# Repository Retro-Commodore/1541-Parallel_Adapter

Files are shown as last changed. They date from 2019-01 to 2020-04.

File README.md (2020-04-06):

# RCEU1505 - 1541-Parallel_Adapter
This is an adapter to easier add a parallel port for the Commodore 1541 and 1541-II diskette drive.
You can (and should) read more on Peter's site https://ist.uwaterloo.ca/~schepers/1541par.html

Item list.
* 15CM 10 wire flatcable.
  * or 8 wire flatcable for ZoomFloppy.
* 15pin D-sub female(not the VGA type connector), either solder or for IDC ribbon cable (last one recommended).
* 40 pins IC socket.
* 2 x 20 pins sil header male-male. (turned/tulip recommended).

All items can be found on eBay or your favorite electronics pusher.

**Let the PCB be as thin as possible, otherwise you need thicker washers. Testet is a 0.8mm thick adapter. **

Washers are needed for the 1541-II drive to lift the mechanical parts.
1.6mm (2 x 0.8mm) height with an inner diameter of 4mm is just sufficient to lift the drive.
It hasn't been physically testet on a 1541 drive, if you're intending to use this drive, let me know how it fits, so I can update this document.

Connecting the adapter to ZoomFloppy is described below, if you need to connect the drive to a C64, you should visit Peter's site for more help.

On 1541 shortboard the chip is UC3, and on the long board it's UAB1.

For solder pins
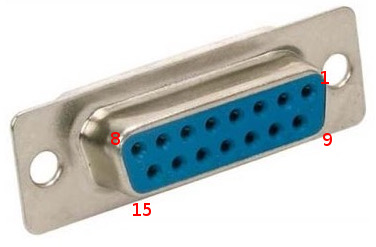
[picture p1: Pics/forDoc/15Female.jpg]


Adapter | 15pin D-sub female
------------ | -------------
Pin 1 | Pin 1
Pin 2 | Pin 2
Pin 3 | Pin 3
Pin 4 | Pin 4
Pin 5 | Pin 5
Pin 6 | Pin 6
Pin 7 | Pin 7
Pin 8 | Pin 8

Soldering the cable for this is just the same pinout

15pin D-sub male | 15pin D-sub female
------------ | -------------
Pin 1 | Pin 1
Pin 2 | Pin 2
Pin 3 | Pin 3
Pin 4 | Pin 4
Pin 5 | Pin 5
Pin 6 | Pin 6
Pin 7 | Pin 7
Pin 8 | Pin 8

If you choose to use the connector to press the IDC connector and don't want to use a 15 pin cable wasting 7 wires, you can hook it up like this.

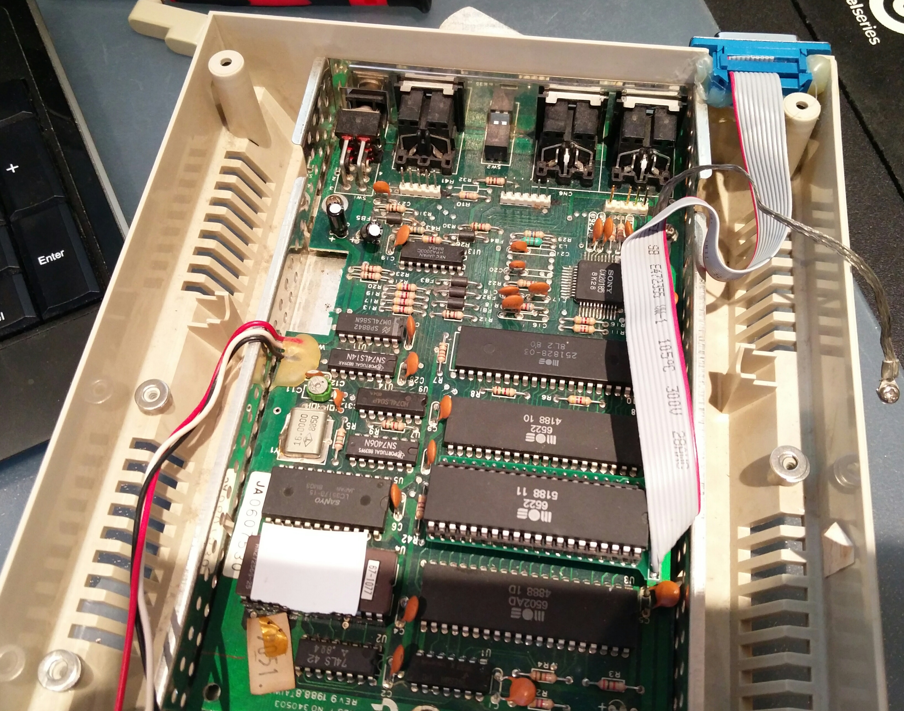
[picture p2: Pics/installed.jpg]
Installed


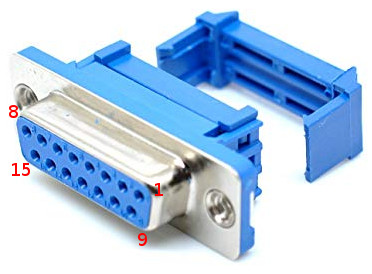
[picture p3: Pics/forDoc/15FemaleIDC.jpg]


Adapter | 15pin D-sub female (IDC)
------------ | -------------
Pin 1 | Pin 1
Pin 2 | Pin 9
Pin 3 | Pin 2
Pin 4 | Pin 10
Pin 5 | Pin 3
Pin 6 | Pin 11
Pin 7 | Pin 4
Pin 8 | Pin 12

The cable should be soldered accordingly

15pin D-sub female | 15pin D-sub male
------------ | -------------
Pin 1 | Pin 1
Pin 2 | Pin 9
Pin 3 | Pin 2
Pin 4 | Pin 10
Pin 5 | Pin 3
Pin 6 | Pin 11
Pin 7 | Pin 4
Pin 8 | Pin 12

Many thanks to [Peter Schepers](https://ist.uwaterloo.ca/~schepers/1541par.html).

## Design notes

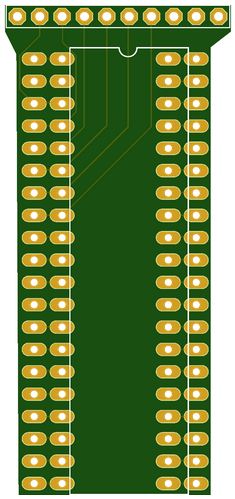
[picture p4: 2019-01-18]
Pics/Top.jpg

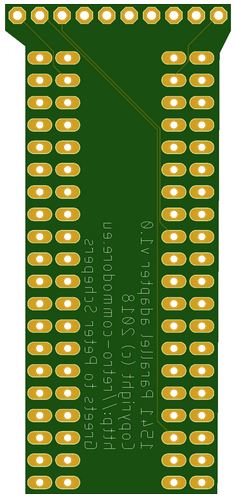
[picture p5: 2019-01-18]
Pics/Bottom.jpg

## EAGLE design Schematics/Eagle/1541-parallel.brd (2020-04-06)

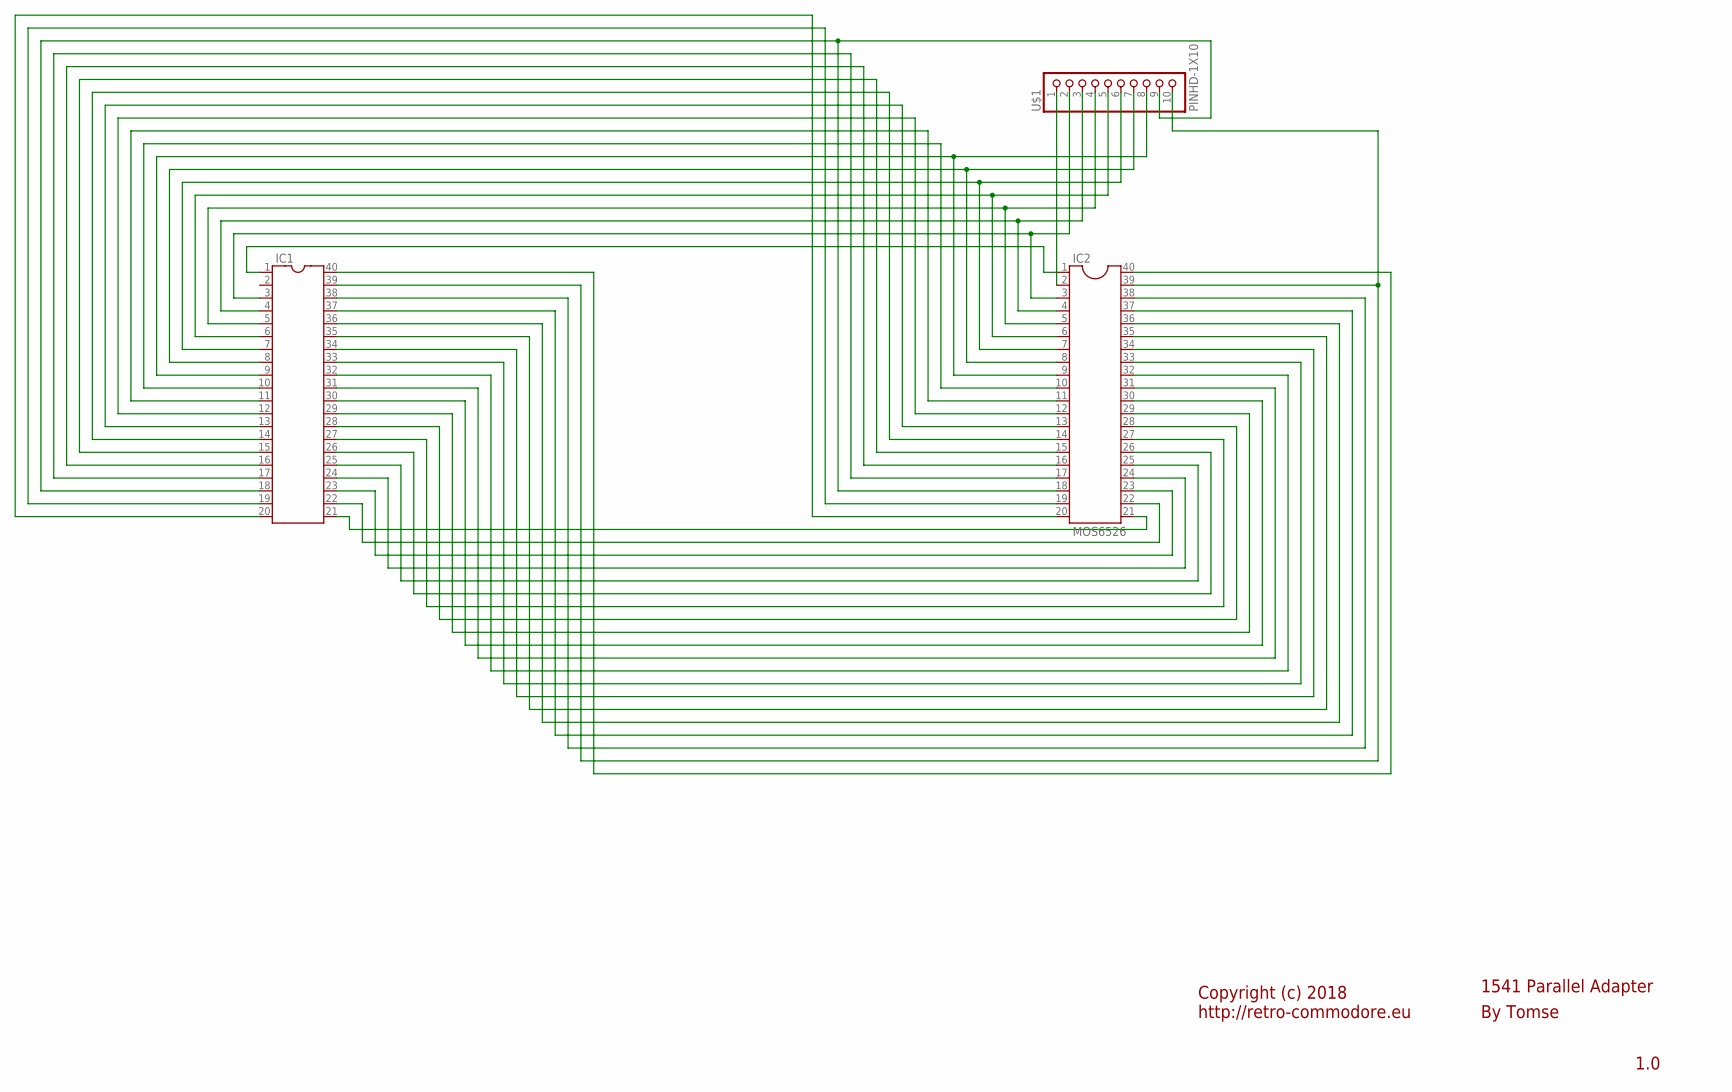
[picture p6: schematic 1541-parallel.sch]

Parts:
IC1: IC-PACKAGE_DIL40
IC2: MOS6526; DIL40
U$1: PINHD-1X10; 1X10-BIG

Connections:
unnamed: IC1.1, IC2.1
unnamed: IC1.3, IC2.3, U$1.2
unnamed: IC1.4, IC2.4, U$1.3
unnamed: IC1.5, IC2.5, U$1.4
unnamed: IC1.6, IC2.6, U$1.5
unnamed: IC1.7, IC2.7, U$1.6
unnamed: IC1.8, IC2.8, U$1.7
unnamed: IC1.9, IC2.9, U$1.8
unnamed: IC1.10, IC2.10
unnamed: IC1.11, IC2.11
unnamed: IC1.12, IC2.12
unnamed: IC1.13, IC2.13
unnamed: IC1.14, IC2.14
unnamed: IC1.15, IC2.15
unnamed: IC1.16, IC2.16
unnamed: IC1.17, IC2.17
unnamed: IC1.18, IC2.18, U$1.9
unnamed: IC1.19, IC2.19
unnamed: IC1.20, IC2.20
unnamed: IC1.21, IC2.21
unnamed: IC1.22, IC2.22
unnamed: IC1.23, IC2.23
unnamed: IC1.24, IC2.24
unnamed: IC1.25, IC2.25
unnamed: IC1.26, IC2.26
unnamed: IC1.27, IC2.27
unnamed: IC1.28, IC2.28
unnamed: IC1.29, IC2.29
unnamed: IC1.30, IC2.30
unnamed: IC1.31, IC2.31
unnamed: IC1.32, IC2.32
unnamed: IC1.33, IC2.33
unnamed: IC1.34, IC2.34
unnamed: IC1.35, IC2.35
unnamed: IC1.36, IC2.36
unnamed: IC1.37, IC2.37
unnamed: IC1.38, IC2.38
unnamed: IC1.39, IC2.39, U$1.10
unnamed: IC1.40, IC2.40
unnamed: IC2.2, U$1.1

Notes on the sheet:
1.0
1541 Parallel Adapter
Copyright (c) 2018 http://retro-commodore.eu
By Tomse

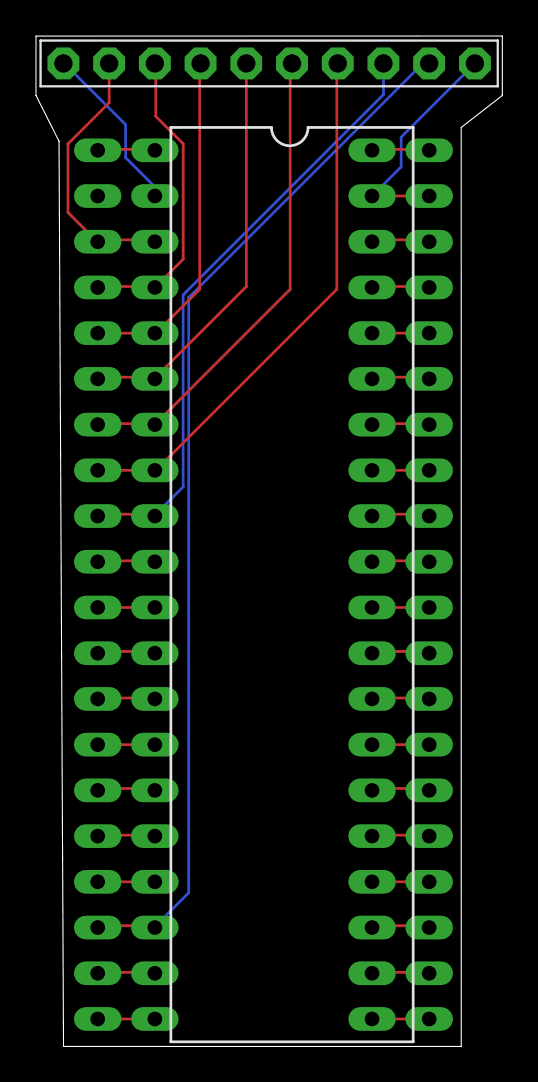
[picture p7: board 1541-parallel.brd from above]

Board: 2 copper layers, 25.9 x 56.1 mm, 3 parts (0 on the bottom side), 40 nets.

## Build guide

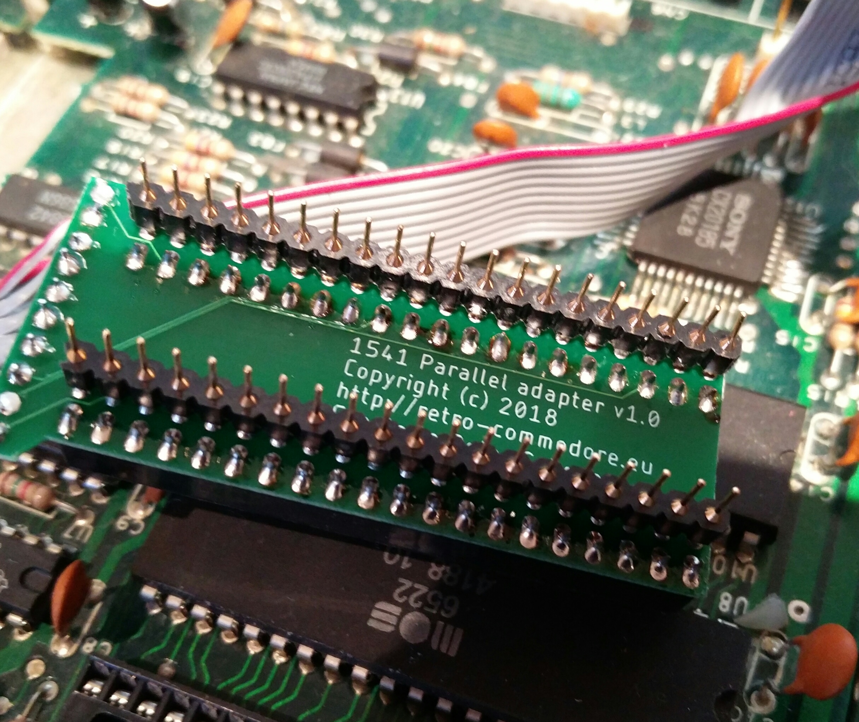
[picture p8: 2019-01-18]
Pics/solderside.jpg

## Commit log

2019-01-18 Initial release
    [1541-parallel.brd, 1541-parallel.sch]
2020-04-06 Fixing dirnaming
    [1541-parallel.brd, 1541-parallel.sch]
2020-04-06 Cosmetic Changes
    [1541-parallel.brd]

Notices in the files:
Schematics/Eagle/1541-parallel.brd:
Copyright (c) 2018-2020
